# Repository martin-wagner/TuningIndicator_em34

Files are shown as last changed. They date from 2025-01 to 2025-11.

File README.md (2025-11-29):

TuningIndicator EM34

# TuningIndicator_EM34

Tube in operation

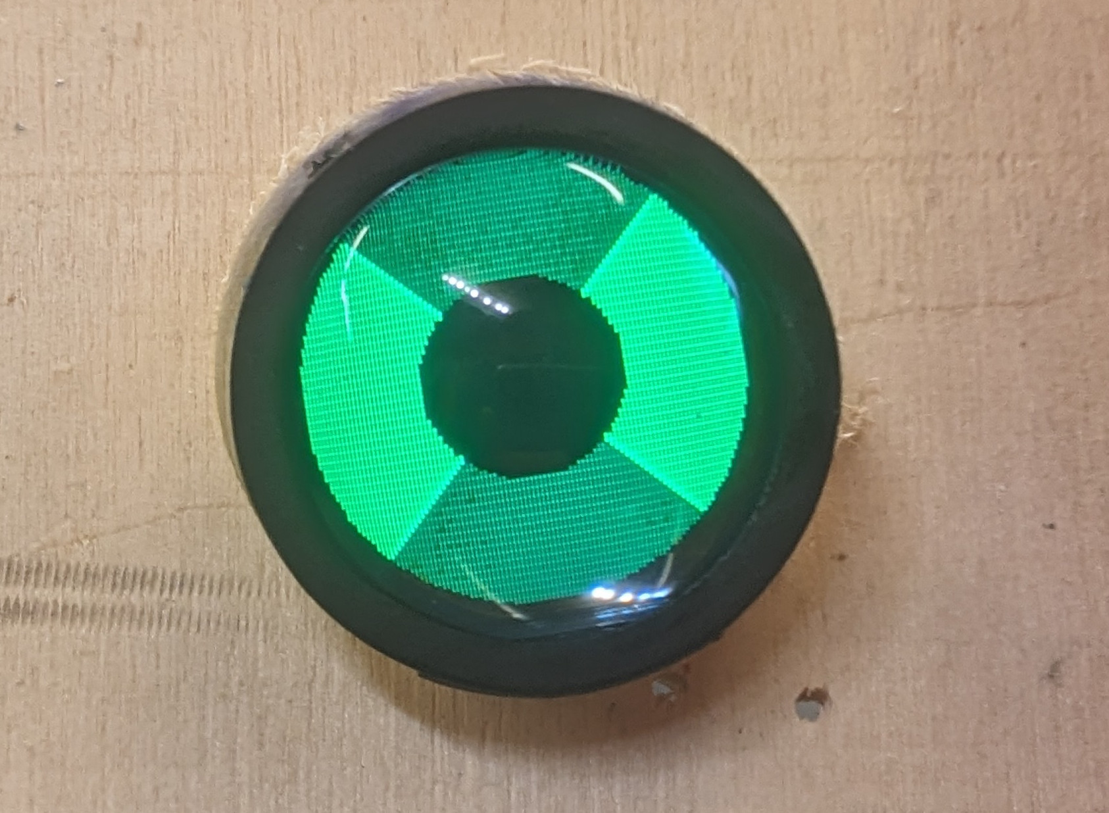
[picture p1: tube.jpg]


Tube in comparision to a Philips EM34

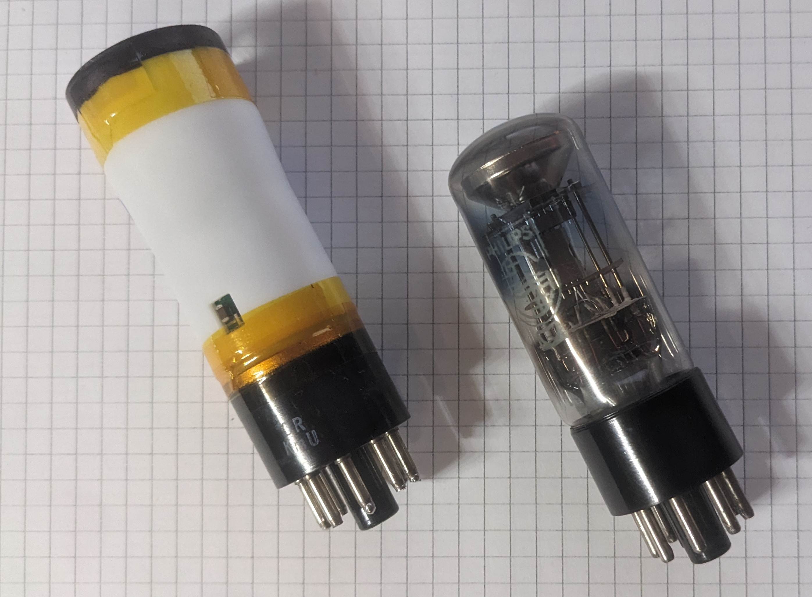
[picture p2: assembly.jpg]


Youtube:

EM34 - Replacement (https://www.youtube.com/watch?v=Ubn03e_z3jU)

## Credits

This project is based on retronics.no 6U5 replacement: https://github.com/donpivo/TuningIndicator_6U5

All PCB design files (KiCAD), fabrication files (gerber), 3D models (.stl) and code (C++, PlatformIO) are shared for personal use only; not for commercial use / sale of neither the complete solution nor parts of it.

## Replacement

The EM34 tube is expensive to buy in good condition and doesn't last that long. "Alternative" tubes only have one shadow angles instead of two.
This project creates a long-lasting tube that mimics the two shadow angles of the EM34, including different sensitivity.

## Building

Follow the guide for the 6U5 tube, it's close enough to the EM34: https://retronics.no/2024/08/29/diy-digital-6u5-magic-eye-replacement/
Be aware to use the EM34 BOM, not the 6U5 one!

### LCD

Can be found on Ebay / Aliexpress for approx. 3 Euro. Search terms: _lcd 0.99 12pin_ . Writing _NFP099-01A_ .

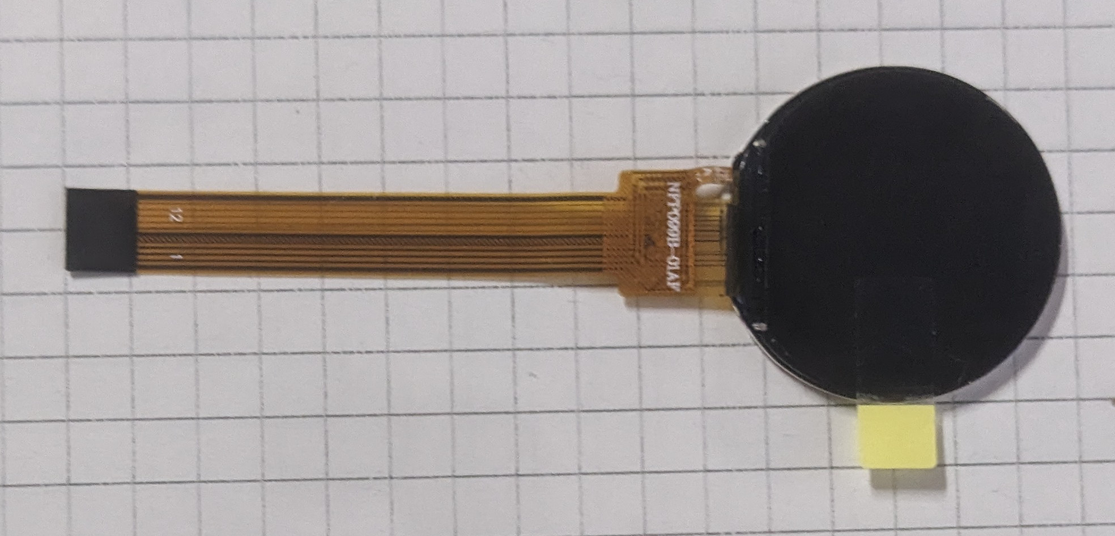
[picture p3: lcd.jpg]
LCD NFP099-01A


### PCB / Housing

Use the gerbers/drill files in cad/pcb/mcu_board/pcb and cad/pcb/octal_base to order at the pcb house of your choise. Use Models/DisplayBracket.stl / Models/EM34-Tube and print/order at the print house of your choise. I've used JLCPCB / JLC3D.

- You need to check your radios schematic for connection of the cathode (see comment in octal_base.pdf).
- I did not use the EMI shield.

### Programming

Use platformio + ST SWD programmer. Either use the programmer on a STM32 devboard or get a ST-LINK/V2 (approx. 15 Euro). Jtag is also exposed on my board, but doesn't have a connector. Use jumper wires to connect SWD to the programmer. The board prints debug info on the serial port.
Be aware that the LCD will not be enabled without pulling the enable pin high (=anode voltage applied)!

### Problems

- The tube is larger compared to a original EM34 (diameter of the top part 30mm instead of 27mm, length 95mm instead of 85mm). Check if your radio will fit a tube of this size!
- The LCD doesn't have good color quality / resolution
- No tube visible when radio is powered off

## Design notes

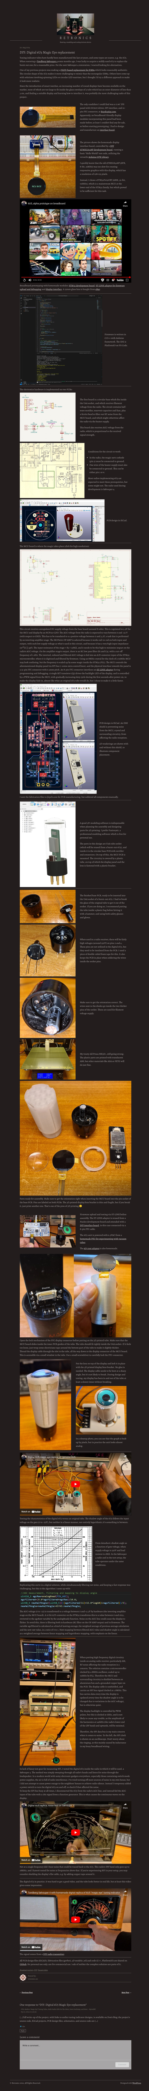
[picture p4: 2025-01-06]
2025-01-06 10.40.33 retronics.no 2fc37c05181f.jpg

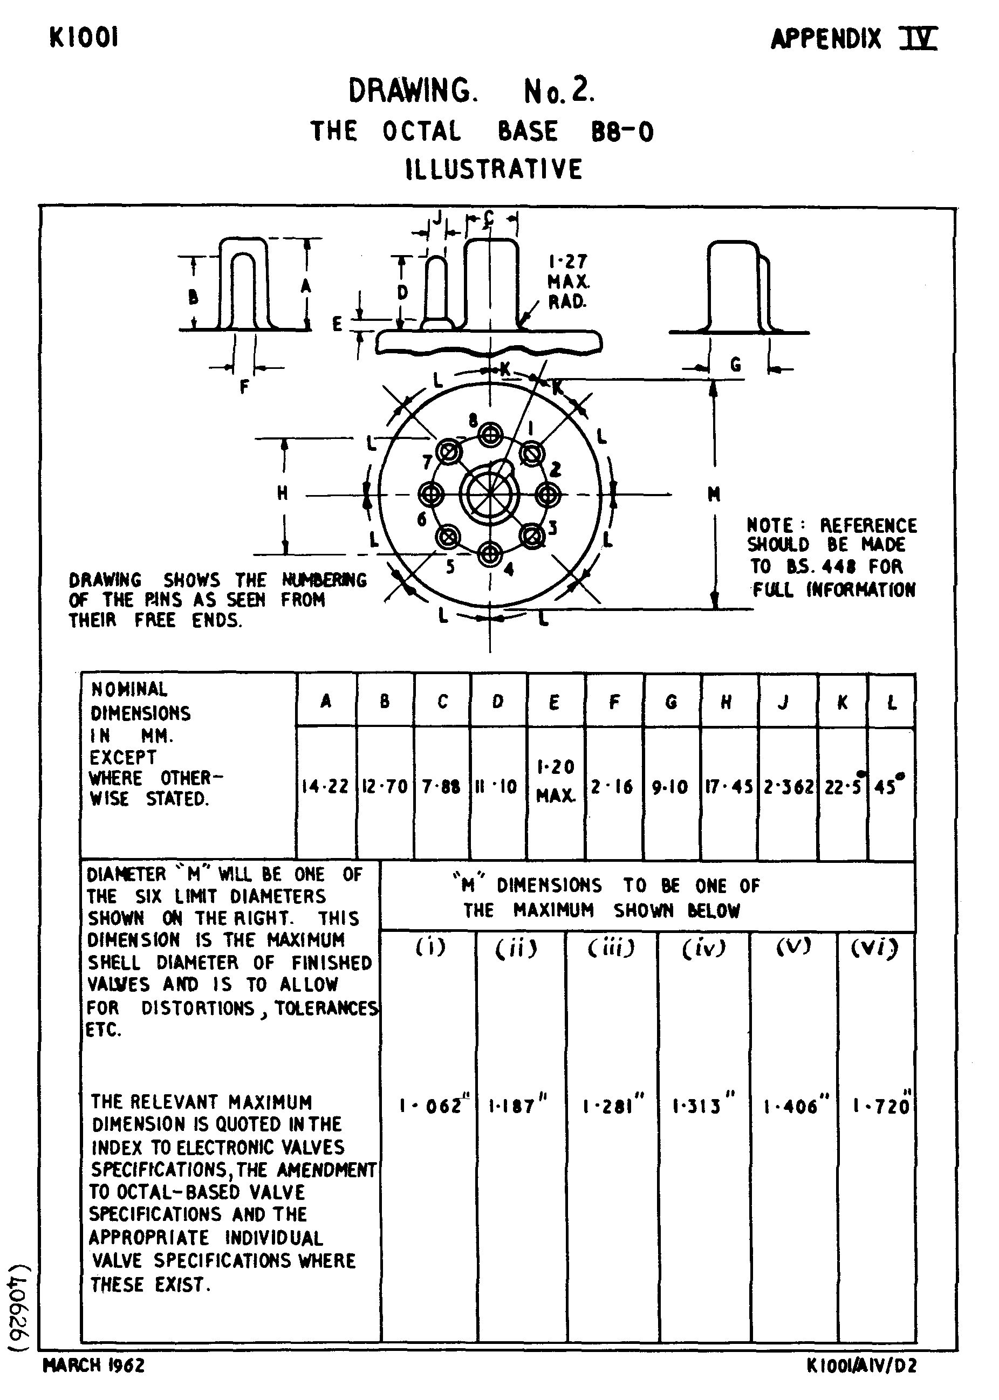
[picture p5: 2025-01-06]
cad/pcb/octal_base/Octal_base.gif

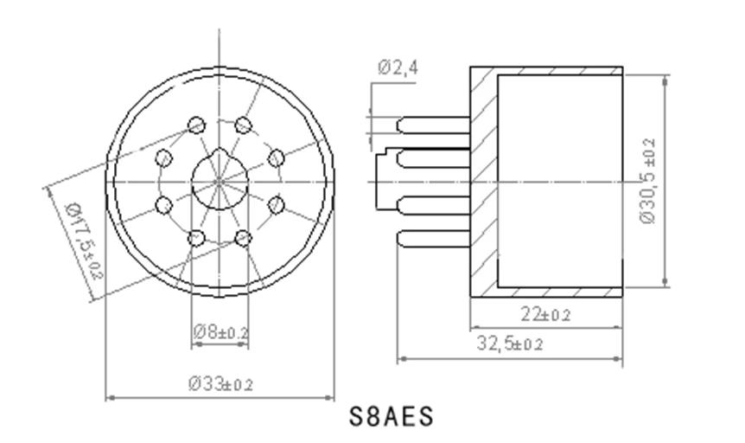
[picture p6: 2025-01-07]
cad/pcb/octal_base/S844fa697d33c40b9b7bb9ba37bb3e9cf7.jpg

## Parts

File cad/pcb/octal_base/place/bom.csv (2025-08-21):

Source: | /home/martin/elektronik/radios/TuningIndicator_em34/cad/pcb/octal_base/octal_base.kicad_sch
Date: | 2025-08-21T12:49:58+0200
Tool: | Eeschema 9.0.4-9.0.4-0~ubuntu24.04.1
Generator: | /usr/share/kicad/plugins/bom_csv_grouped_by_value.py
Component Count: | 11
Collated Components:
Item | Qty | Reference(s) | Value | LibPart | Footprint | Datasheet | DNP | Comments | Datasheet | Description | Footprint | Placement
1 | 1 | C1 | 1000µF 16V | Device:C_Polarized | CP_Radial_D8.0mm_P3.50mm_H21mm | ~ |  |  | ~ | Polarized capacitor | CP_Radial_D8.0mm_P3.50mm_H21mm
2 | 1 | D1 | 3.3V | Device:D_Zener | Diode_SMD:D_0603_1608Metric_Pad1.05x0.95mm_HandSolder | ~ |  |  | ~ | Zener diode | Diode_SMD:D_0603_1608Metric_Pad1.05x0.95mm_HandSolder
3 | 2 | D2, D3 | 1N5819W | Diode:1N5819WS | D_SOD-323_HandSoldering | https://datasheet.lcsc.com/lcsc/2204281430_Guangdong-Hottech-1N5819WS_C191023.pdf |  |  | https://datasheet.lcsc.com/lcsc/2204281430_Guangdong-Hottech-1N5819WS_C191023.pdf | 40V 600mV@1A 1A SOD-323 Schottky Barrier Diodes, SOD-323 | D_SOD-323_HandSoldering
4 | 1 | F1 | T1A | Device:Fuse | Fuse_1206_3216Metric | ~ |  |  | ~ | Fuse | Fuse_1206_3216Metric
5 | 1 | FB1 | 330Ω@100MHz | Device:FerriteBead | L_0805_2012Metric_Pad1.15x1.40mm_HandSolder | ~ |  | 50mΩ@DC | ~ | Ferrite bead | L_0805_2012Metric_Pad1.15x1.40mm_HandSolder
6 | 1 | J1 | Octal Base | Connector_Generic:Conn_01x08 | Library:Valve_Octal_Base | ~ |  |  | ~ | Generic connector, single row, 01x08, script generated (kicad-library-utils/schlib/autogen/connector/) | Library:Valve_Octal_Base
7 | 1 | J2 | Pin Socket | Connector:Conn_01x05_Socket | PinSocket_1x05_P2.54mm_Vertical | ~ |  |  | ~ | Generic connector, single row, 01x05, script generated | PinSocket_1x05_P2.54mm_Vertical
8 | 1 | R1 | 1M | Device:R | Resistor_SMD:R_1206_3216Metric_Pad1.30x1.75mm_HandSolder | ~ |  |  | ~ | Resistor | Resistor_SMD:R_1206_3216Metric_Pad1.30x1.75mm_HandSolder
9 | 1 | R2 | 4k7 | Device:R | Resistor_SMD:R_0603_1608Metric_Pad0.98x0.95mm_HandSolder | ~ |  |  | ~ | Resistor | Resistor_SMD:R_0603_1608Metric_Pad0.98x0.95mm_HandSolder | NP
10 | 1 | R3 | 0 | Device:R | Resistor_SMD:R_0603_1608Metric_Pad0.98x0.95mm_HandSolder | ~ |  |  | ~ | Resistor | Resistor_SMD:R_0603_1608Metric_Pad0.98x0.95mm_HandSolder

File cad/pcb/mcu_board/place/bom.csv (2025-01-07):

Source: | /home/martin/elektronik/radios/TuningIndicator_em34/cad/pcb/mcu_board/mcu_board.kicad_sch
Date: | 2025-01-07T12:11:06+0100
Tool: | Eeschema 8.0.7-8.0.7-0~ubuntu22.04.1
Generator: | /usr/share/kicad/plugins/bom_csv_grouped_by_value.py
Component Count: | 40
Collated Components:
Item | Qty | Reference(s) | Value | LibPart | Footprint | Datasheet | DNP | Comments | Datasheet | Description | Footprint | Place
1 | 1 | C1 | 10µF | Device:C_Small | Capacitor_SMD:C_1206_3216Metric_Pad1.33x1.80mm_HandSolder | ~ |  |  | ~ | Unpolarized capacitor, small symbol | Capacitor_SMD:C_1206_3216Metric_Pad1.33x1.80mm_HandSolder
2 | 1 | C2 | 100nF | Device:C | Retronics_Passives:C_0603_1608Metric_Pad1.08x0.95mm_HandSolder | ~ |  |  | ~ | Unpolarized capacitor | Retronics_Passives:C_0603_1608Metric_Pad1.08x0.95mm_HandSolder
3 | 4 | C3, C9, C10, C11 | 100nF | Device:C_Small | Capacitor_SMD:C_0603_1608Metric_Pad1.08x0.95mm_HandSolder | ~ |  |  | ~ | Unpolarized capacitor, small symbol | Capacitor_SMD:C_0603_1608Metric_Pad1.08x0.95mm_HandSolder
4 | 3 | C4, C5, C6 | 10µF | Device:C | Capacitor_SMD:C_1206_3216Metric_Pad1.33x1.80mm_HandSolder | ~ |  |  | ~ | Unpolarized capacitor | Capacitor_SMD:C_1206_3216Metric_Pad1.33x1.80mm_HandSolder
5 | 2 | C7, C8 | 20pF | Device:C_Small | Capacitor_SMD:C_0603_1608Metric_Pad1.08x0.95mm_HandSolder | ~ |  |  | ~ | Unpolarized capacitor, small symbol | Capacitor_SMD:C_0603_1608Metric_Pad1.08x0.95mm_HandSolder
6 | 1 | FB1 | 1kΩ@100MHz 500mΩ@DC | Device:FerriteBead_Small | Inductor_SMD:L_0603_1608Metric_Pad1.05x0.95mm_HandSolder | ~ |  |  | ~ | Ferrite bead, small symbol | Inductor_SMD:L_0603_1608Metric_Pad1.05x0.95mm_HandSolder
7 | 1 | J1 | Pin Header | Connector:Conn_01x05_Pin | Connector_PinHeader_2.54mm:PinHeader_1x05_P2.54mm_Horizontal | ~ |  |  | ~ | Generic connector, single row, 01x05, script generated | Connector_PinHeader_2.54mm:PinHeader_1x05_P2.54mm_Horizontal
8 | 1 | J2 | EMI Shield | Connector_Generic:Conn_01x01 | Retronics_Hardware:EMI_Shield_MS207-10S | ~ |  |  | ~ | Generic connector, single row, 01x01, script generated (kicad-library-utils/schlib/autogen/connector/) | Retronics_Hardware:EMI_Shield_MS207-10S
9 | 6 | J3, J4, J6, J8, J9, J10 | Conn_01x01_Pin | Connector:Conn_01x01_Pin | TestPoint:TestPoint_Pad_D1.5mm | ~ |  |  | ~ | JTMS | TestPoint:TestPoint_Pad_D1.5mm
10 | 1 | J5 | Display interface | Connector_Generic:Conn_01x12 | Retronics_Connectors:505110-1292 | ~ |  |  | ~ | Generic connector, single row, 01x12, script generated (kicad-library-utils/schlib/autogen/connector/) | Retronics_Connectors:505110-1292
11 | 1 | J7 | FFC8 | Connector_Generic:Conn_01x08 | Connector_PinHeader_2.54mm:PinHeader_1x08_P2.54mm_Vertical | ~ |  |  | ~ | Generic connector, single row, 01x08, script generated (kicad-library-utils/schlib/autogen/connector/) | Connector_PinHeader_2.54mm:PinHeader_1x08_P2.54mm_Vertical
12 | 1 | Q1 | BC847C | Transistor_BJT:BC847 | Retronics_Discrete:SOT-23 | http://www.infineon.com/dgdl/Infineon-BC847SERIES_BC848SERIES_BC849SERIES_BC850SERIES-DS-v01_01-en.pdf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 |  |  | http://www.infineon.com/dgdl/Infineon-BC847SERIES_BC848SERIES_BC849SERIES_BC850SERIES-DS-v01_01-en.pdf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 | 0.1A Ic, 45V Vce, NPN Transistor, SOT-23 | Retronics_Discrete:SOT-23
13 | 1 | R1 | 10kΩ | Device:R | Retronics_Passives:R_0603_1608Metric_Pad0.98x0.95mm_HandSolder | ~ |  |  | ~ | Resistor | Retronics_Passives:R_0603_1608Metric_Pad0.98x0.95mm_HandSolder
14 | 1 | R2 | 2.2MΩ | Device:R | Retronics_Passives:R_0603_1608Metric_Pad0.98x0.95mm_HandSolder | ~ |  |  | ~ | Resistor | Retronics_Passives:R_0603_1608Metric_Pad0.98x0.95mm_HandSolder
15 | 1 | R3 | 15MΩ | Device:R | Retronics_Passives:R_0603_1608Metric_Pad0.98x0.95mm_HandSolder | ~ |  |  | ~ | Resistor | Retronics_Passives:R_0603_1608Metric_Pad0.98x0.95mm_HandSolder
16 | 1 | R4 | 10kΩ | Device:R_Small | Resistor_SMD:R_0603_1608Metric_Pad0.98x0.95mm_HandSolder | ~ |  |  | ~ | Resistor, small symbol | Resistor_SMD:R_0603_1608Metric_Pad0.98x0.95mm_HandSolder
17 | 1 | R5 | 2k7 | Device:R | Resistor_SMD:R_0603_1608Metric_Pad0.98x0.95mm_HandSolder | ~ |  |  | ~ | Resistor | Resistor_SMD:R_0603_1608Metric_Pad0.98x0.95mm_HandSolder
18 | 4 | R6, R7, R8, R9 | 0 | Device:R | Resistor_SMD:R_0603_1608Metric_Pad0.98x0.95mm_HandSolder | ~ |  |  | ~ | Resistor | Resistor_SMD:R_0603_1608Metric_Pad0.98x0.95mm_HandSolder | NP
19 | 1 | R10 | 4k7 | Device:R | Resistor_SMD:R_0603_1608Metric_Pad0.98x0.95mm_HandSolder | ~ |  |  | ~ | Resistor | Resistor_SMD:R_0603_1608Metric_Pad0.98x0.95mm_HandSolder
20 | 1 | R11 | 1MΩ | Device:R_Small | Resistor_SMD:R_0603_1608Metric_Pad0.98x0.95mm_HandSolder | ~ |  |  | ~ | Resistor, small symbol | Resistor_SMD:R_0603_1608Metric_Pad0.98x0.95mm_HandSolder
21 | 1 | R12 | 10Ω | Device:R_Small | Resistor_SMD:R_0603_1608Metric_Pad0.98x0.95mm_HandSolder | ~ |  |  | ~ | Resistor, small symbol | Resistor_SMD:R_0603_1608Metric_Pad0.98x0.95mm_HandSolder
22 | 1 | R13 | 1kΩ | Device:R_Small | Resistor_SMD:R_0603_1608Metric_Pad0.98x0.95mm_HandSolder | ~ |  |  | ~ | Resistor, small symbol | Resistor_SMD:R_0603_1608Metric_Pad0.98x0.95mm_HandSolder
23 | 1 | U1 | MCP6001T-I/OT | Amplifier_Operational:MCP601-xOT | Retronics_IC:SOT-23-5 | http://ww1.microchip.com/downloads/en/DeviceDoc/21314g.pdf |  |  | http://ww1.microchip.com/downloads/en/DeviceDoc/21314g.pdf | Single 2.7V to 6.0V Single Supply CMOS Op Amps, SOT-23-5 | Retronics_IC:SOT-23-5
24 | 1 | U2 | STM32F303CBTx | Retronics_Microcontrollers:STM32F103Cx | Package_QFP:LQFP-48_7x7mm_P0.5mm | http://www.st.com/st-web-ui/static/active/en/resource/technical/document/datasheet/CD00161566.pdf |  |  | http://www.st.com/st-web-ui/static/active/en/resource/technical/document/datasheet/CD00161566.pdf | ARM Cortex-M4 MCU, 128KB flash, 40KB RAM, 72MHz, 2-3.6V, 37 GPIO, LQFP-48 | Package_QFP:LQFP-48_7x7mm_P0.5mm
25 | 1 | U3 | NCP1117-Adj_SOT223 | Regulator_Linear:NCP1117-5.0_SOT223 | Retronics_IC_Power:SOT-223-3_TabPin2 | http://www.onsemi.com/pub_link/Collateral/NCP1117-D.PDF |  |  | http://www.onsemi.com/pub_link/Collateral/NCP1117-D.PDF | 1A Low drop-out regulator, Fixed Output 5V, SOT-223 | Retronics_IC_Power:SOT-223-3_TabPin2
26 | 1 | Y1 | XC32M4-8.000 12pF | Device:Crystal_GND24_Small | Crystal:Crystal_SMD_3225-4Pin_3.2x2.5mm | ~ |  |  | ~ | Four pin crystal, GND on pins 2 and 4, small symbol | Crystal:Crystal_SMD_3225-4Pin_3.2x2.5mm

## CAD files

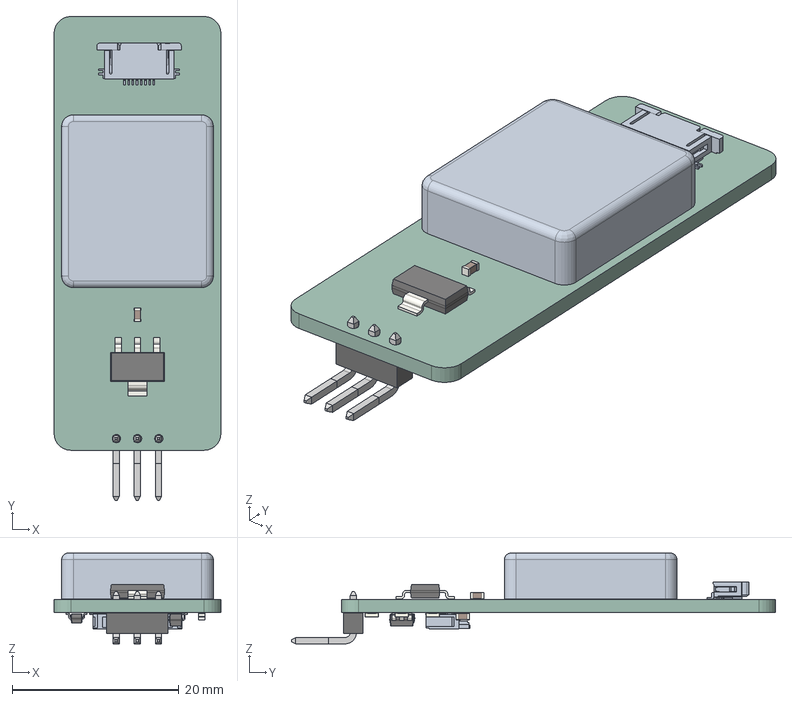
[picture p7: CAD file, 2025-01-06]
cad/pcb/mcu_board/mcu_board.step
20.0 x 58.0 x 10.9 mm
MS207-10S
SOT_223
C_0603_1608Metric x 3
R_0603_1608Metric x 3
SOT_23
SOT_23_5
PinHeader_022052031 v4
U6A_MCU_Board_PCB

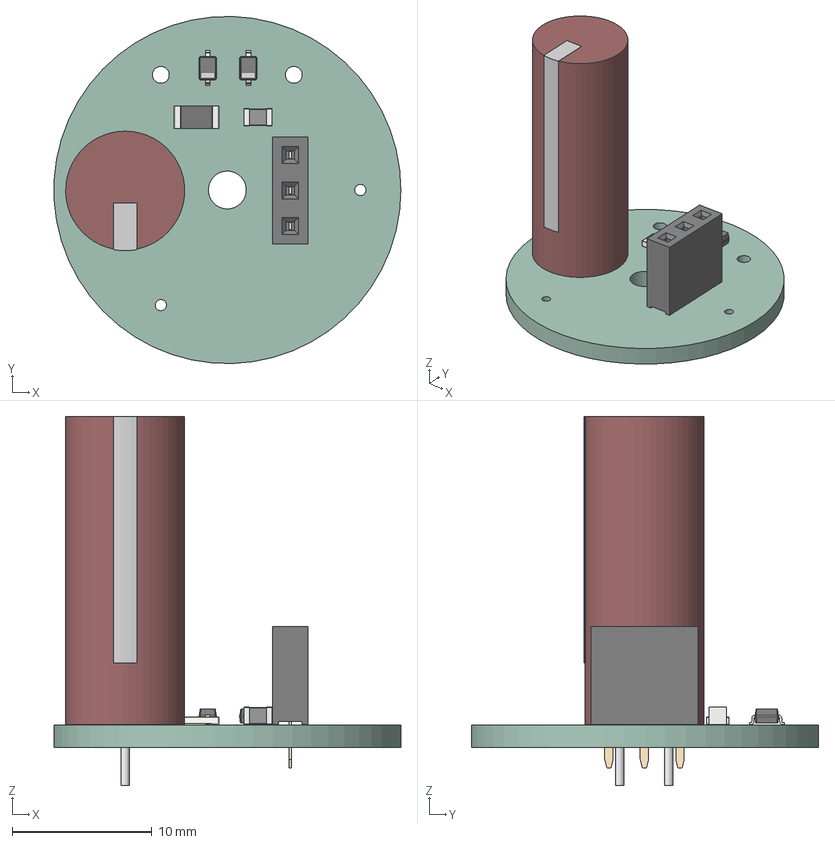
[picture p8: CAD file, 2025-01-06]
cad/pcb/octal_base/octal_base.step
24.8 x 24.8 x 26.4 mm
D_SOD_323 x 2
Fuse_1206_3216Metric
L_0805_2012Metric
PinSocket_1x03_P254mm_Vertical
U6A_Base_PCB

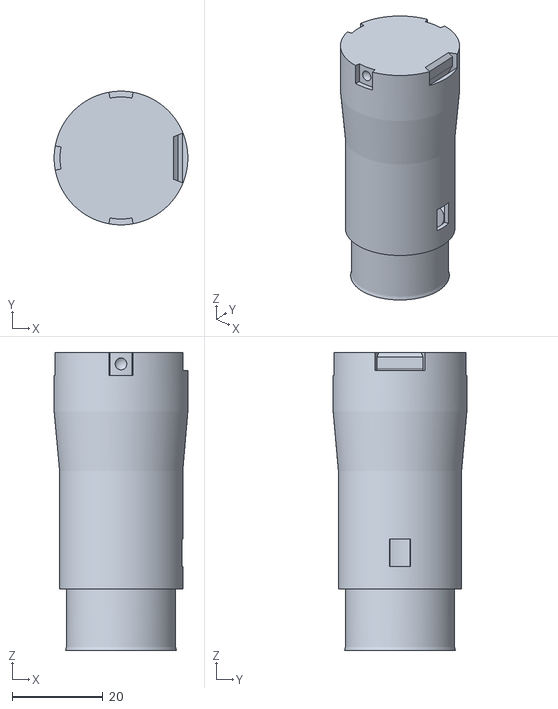
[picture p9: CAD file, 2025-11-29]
Models/em34-Tube.stl
29.4 x 29.4 x 65.5

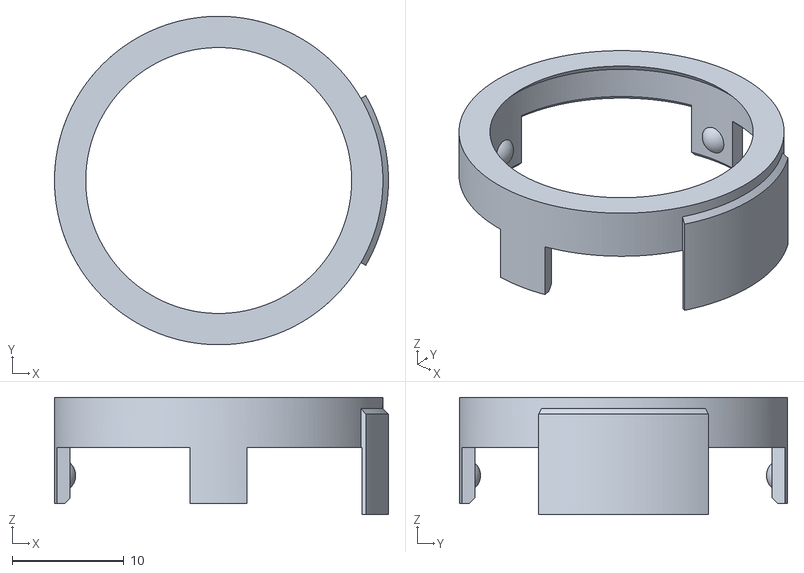
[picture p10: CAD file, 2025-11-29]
Models/DisplayBracket.stl
29.9 x 29.4 x 10.5

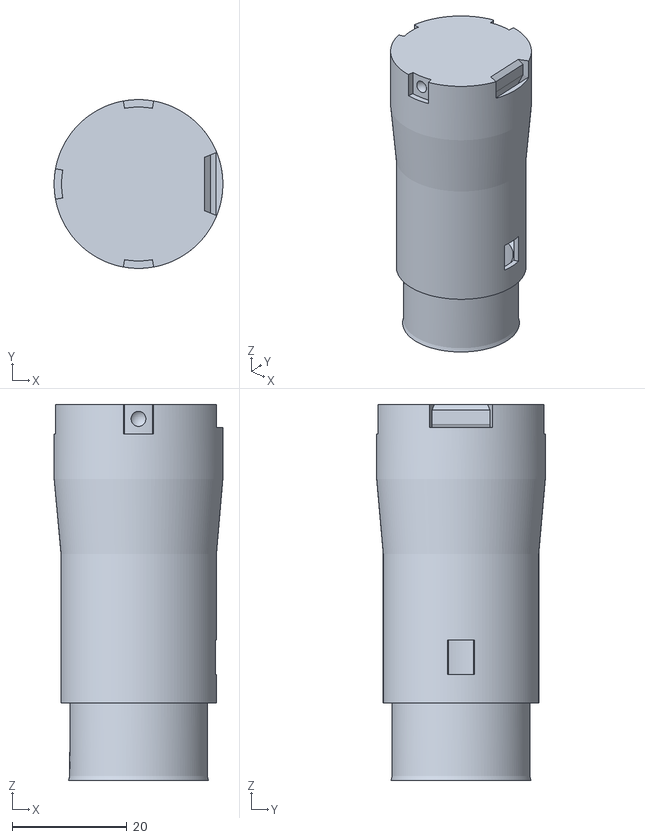
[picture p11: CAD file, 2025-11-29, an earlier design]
Models/archiv/em34-chatgpt.stl
29.4 x 29.4 x 65.5

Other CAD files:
Models/archiv/em34-freecad.FCStd
Models/archiv/6U5_Tube.stl

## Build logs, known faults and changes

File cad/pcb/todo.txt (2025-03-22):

scm

pcb

pcb aufdruck em>>8<<4
pcb aufdruck pin1 lcd fehlt
elko passt nicht
Stecker Debug SWG GND zwischen DIO und CLK, sonst verbindet SWD nicht.

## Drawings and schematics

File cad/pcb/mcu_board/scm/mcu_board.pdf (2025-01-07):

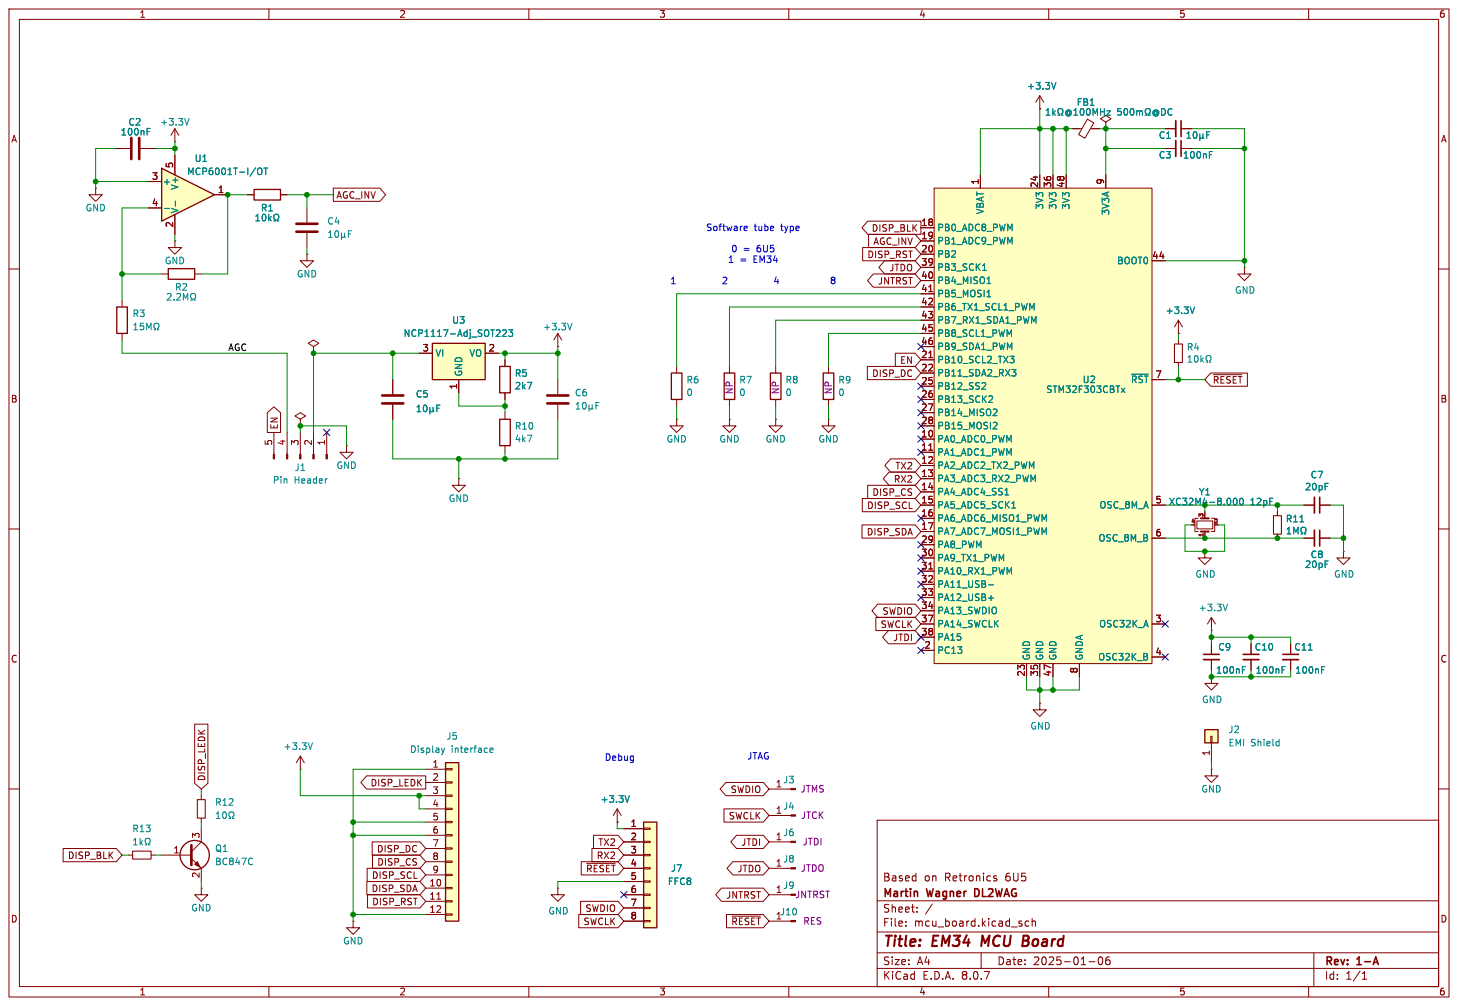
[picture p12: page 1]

1 PA0_ADC0_PWM 10 PA1_ADC1_PWM 11 PA2_ADC2_TX2_PWM 12 PA3_ADC3_RX2_PWM 13 PA4_ADC4_SS1 14 PA5_ADC5_SCK1 15 PA6_ADC6_MISO1_PWM 16 PA7_ADC7_MOSI1_PWM 17 PB0_ADC8_PWM 18 PB1_ADC9_PWM 19 PC13 2 PB2 20 PB10_SCL2_TX3 21 PB11_SDA2_RX3 22 GND 23 3V3 24 PB12_SS2 25 PB13_SCK2 26 PB14_MISO2 27 PB15_MOSI2 28 PA8_PWM 29 OSC32K_A 3 PA9_TX1_PWM 30 PA10_RX1_PWM 31 PA11_USB- 32 PA12_USB+ 33 PA13_SWDIO 34 GND 35 3V3 36 PA14_SWCLK 37 PA15 38 PB3_SCK1 39 OSC32K_B 4 PB4_MISO1 40 PB5_MOSI1 41 PB6_TX1_SCL1_PWM 42 PB7_RX1_SDA1_PWM 43 BOOT0 44 PB8_SCL1_PWM 45 PB9_SDA1_PWM 46 GND 47 3V3 48 OSC_8M_A 5 OSC_8M_B 6 ~{RST}7 GNDA

Id: 1/1 Title: EM34 MCU Board

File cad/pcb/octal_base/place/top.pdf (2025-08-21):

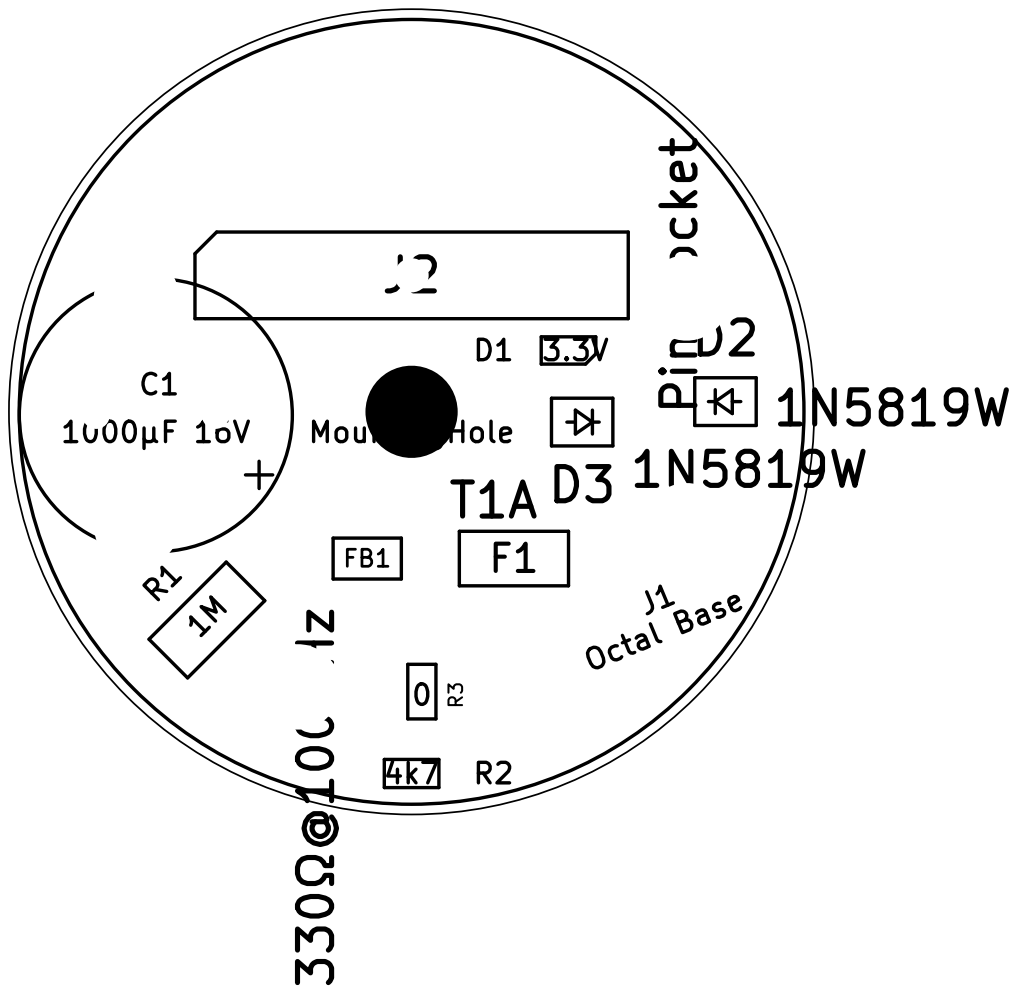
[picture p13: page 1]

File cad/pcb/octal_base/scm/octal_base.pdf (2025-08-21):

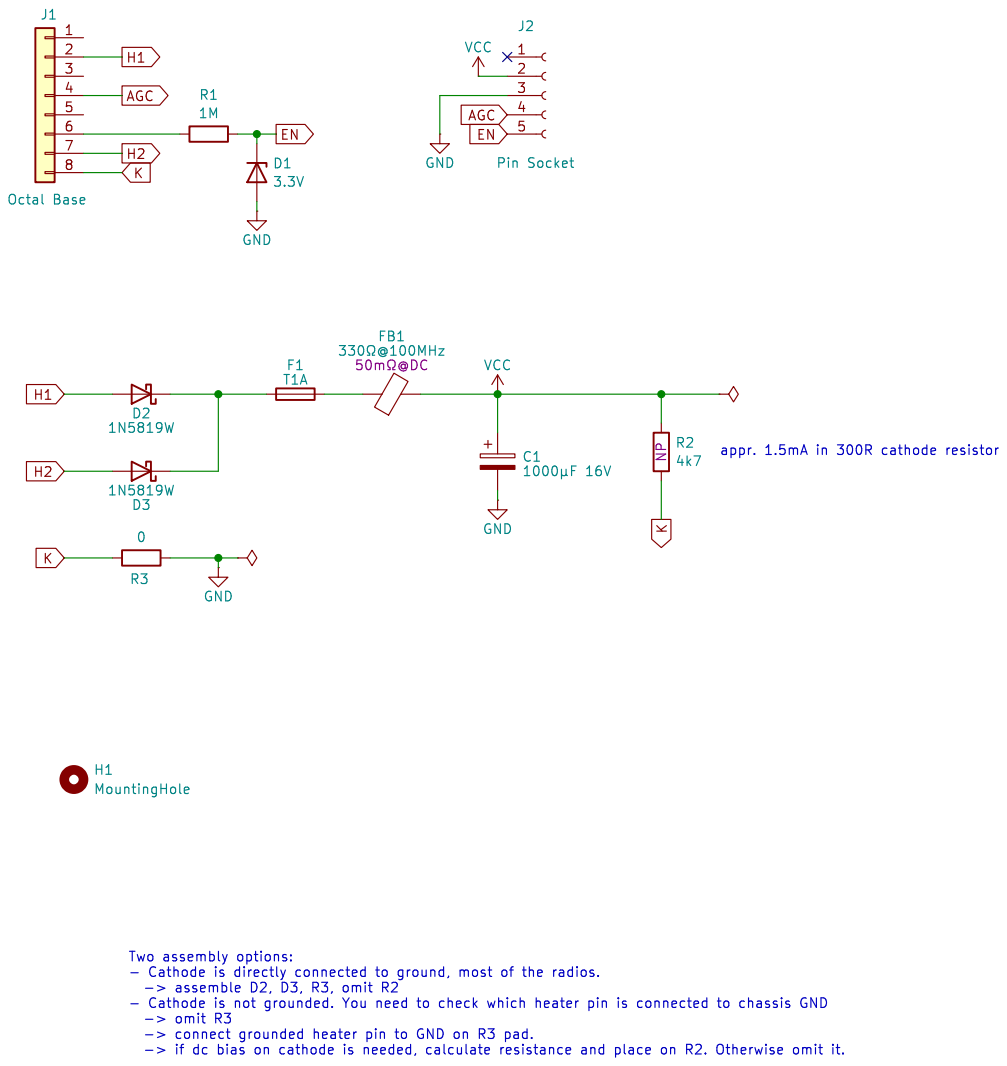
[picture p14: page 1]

Id: 1/1 Title: Adaptor octal base

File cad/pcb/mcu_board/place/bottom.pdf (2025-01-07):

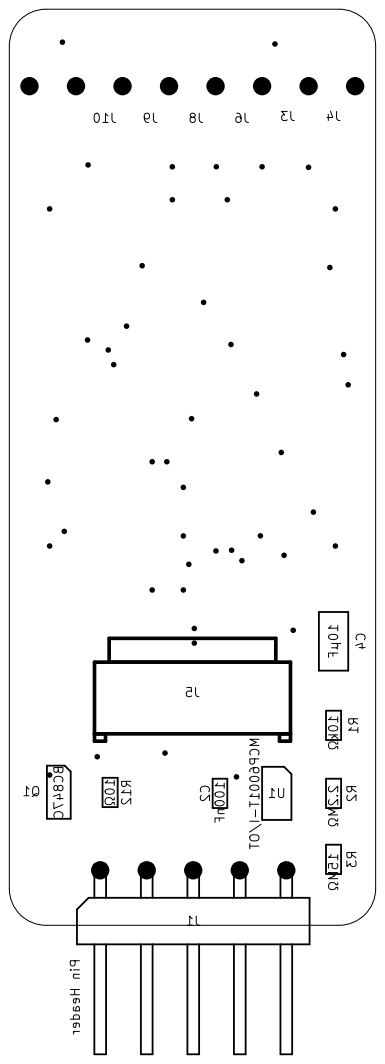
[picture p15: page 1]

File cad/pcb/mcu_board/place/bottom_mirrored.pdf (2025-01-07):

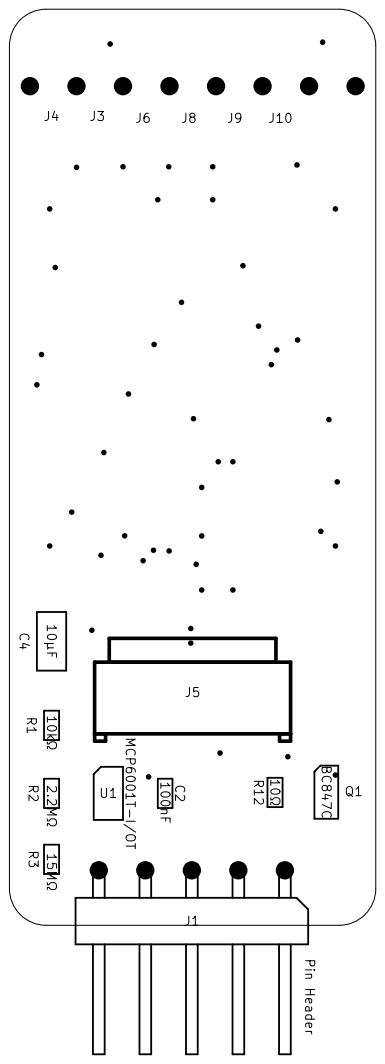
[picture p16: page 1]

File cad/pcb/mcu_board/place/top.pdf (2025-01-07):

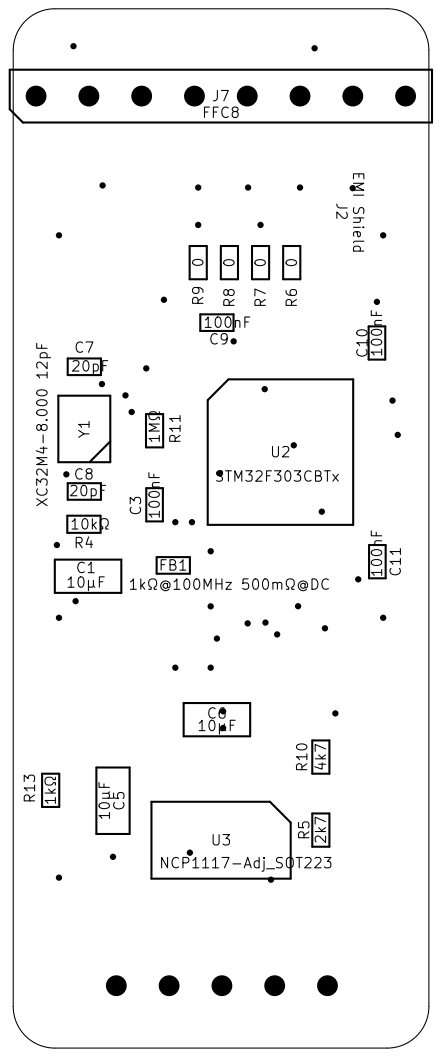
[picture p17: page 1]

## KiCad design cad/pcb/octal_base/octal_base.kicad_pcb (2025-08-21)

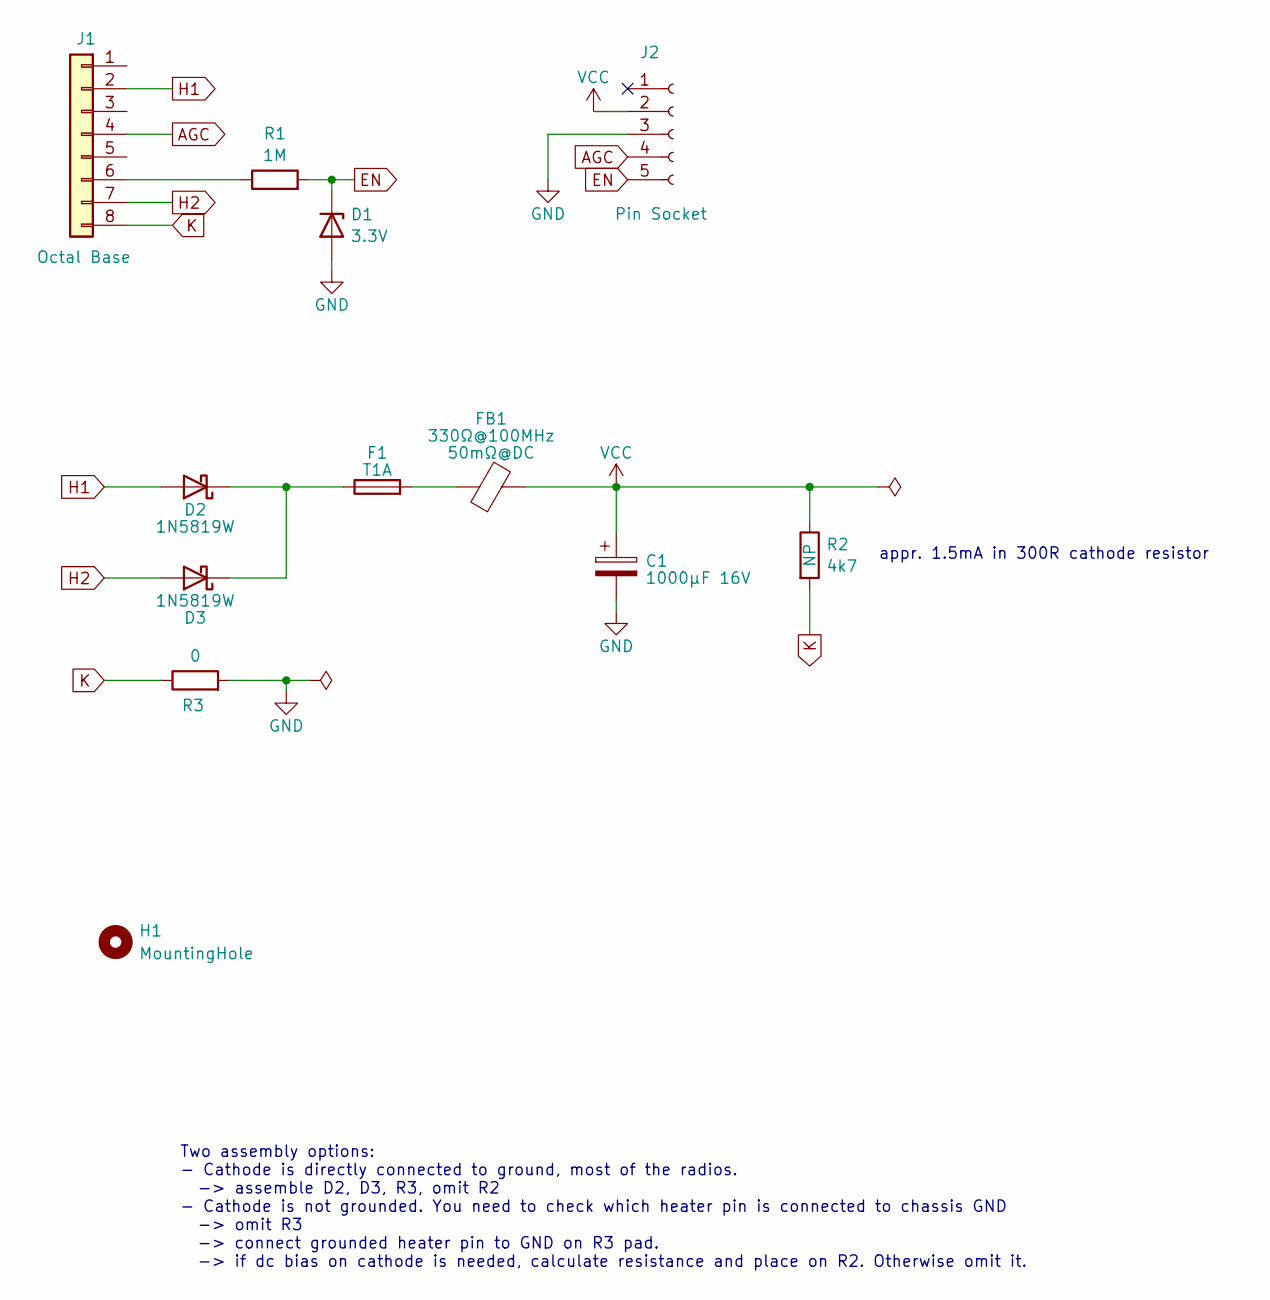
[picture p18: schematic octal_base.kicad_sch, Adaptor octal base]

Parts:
C1: 1000µF 16V; CP_Radial_D8.0mm_P3.50mm_H21mm
D1: 3.3V; D_0603_1608Metric_Pad1.05x0.95mm_HandSolder
D2, D3: 1N5819W; D_SOD-323_HandSoldering
F1: T1A; Fuse_1206_3216Metric
FB1: 330Ω@100MHz; L_0805_2012Metric_Pad1.15x1.40mm_HandSolder
H1: MountingHole; MountingHole_2.7mm_M2.5
J1: Octal Base; Valve_Octal_Base
J2: Pin Socket; PinSocket_1x05_P2.54mm_Vertical
R1: 1M; R_1206_3216Metric_Pad1.30x1.75mm_HandSolder
R2: 4k7; R_0603_1608Metric_Pad0.98x0.95mm_HandSolder
R3: 0; R_0603_1608Metric_Pad0.98x0.95mm_HandSolder

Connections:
AGC: J1.4, J2.4
EN: D1.1 (K), J2.5, R1.2
GND: C1.2, D1.2 (A), J2.3, R3.2
H1: D2.2 (A), J1.2
H2: D3.2 (A), J1.7
K: J1.8, R2.2, R3.1
unnamed: D2.1 (K), D3.1 (K), F1.1
unnamed: F1.2, FB1.1
unnamed: J1.6, R1.1
VCC: C1.1, FB1.2, J2.2, R2.1

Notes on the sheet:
appr. 1.5mA in 300R cathode resistor
Two assembly options: - Cathode is directly connected to ground, most of the radios. -> assemble D2, D3, R3, omit R2 - Cathode is not grounded. You need to check which heater pin is connected to chassis GND -> omit R3 -> connect grounded heater pin to GND on R3 pad. -> if dc bias on cathode is need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

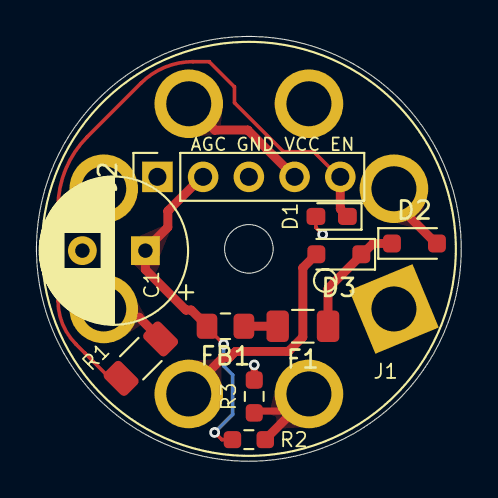
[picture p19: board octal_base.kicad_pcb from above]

Board: 2 copper layers, 23.6 x 23.6 mm, 12 parts (0 on the bottom side), 10 nets.

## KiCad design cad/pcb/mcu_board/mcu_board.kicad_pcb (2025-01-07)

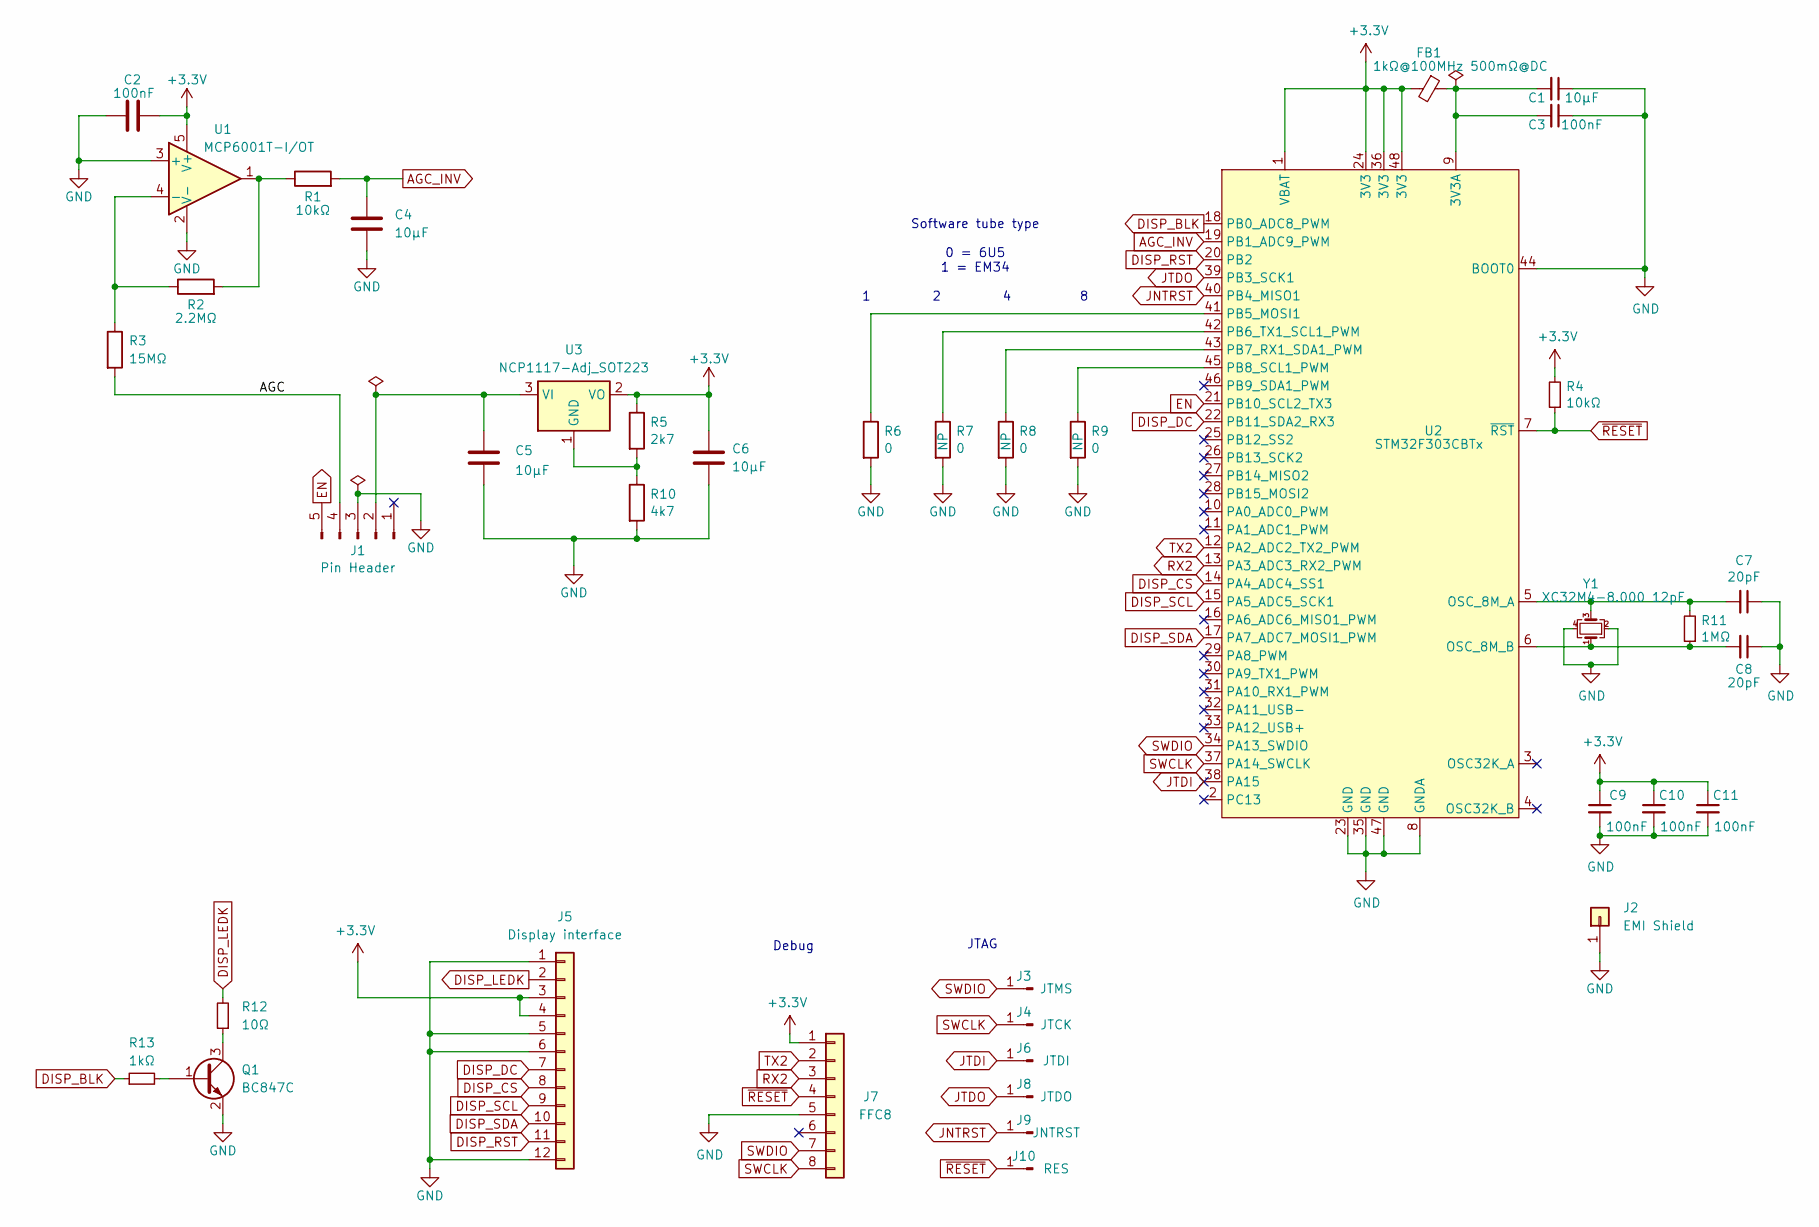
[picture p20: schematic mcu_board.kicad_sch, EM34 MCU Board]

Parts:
C1, C4, C5, C6: 10µF; C_1206_3216Metric_Pad1.33x1.80mm_HandSolder
C2, C3, C9, C10, C11: 100nF; C_0603_1608Metric_Pad1.08x0.95mm_HandSolder
C7, C8: 20pF; C_0603_1608Metric_Pad1.08x0.95mm_HandSolder
FB1: 1kΩ@100MHz 500mΩ@DC; L_0603_1608Metric_Pad1.05x0.95mm_HandSolder
J1: Pin Header; PinHeader_1x05_P2.54mm_Horizontal
J2: EMI Shield; EMI_Shield_MS207-10S
J3, J4, J6, J8, J9, J10: Conn_01x01_Pin; TestPoint_Pad_D1.5mm
J5: Display interface; 505110-1292
J7: FFC8; PinHeader_1x08_P2.54mm_Vertical
Q1: BC847C; SOT-23
R1, R4: 10kΩ; R_0603_1608Metric_Pad0.98x0.95mm_HandSolder
R2: 2.2MΩ; R_0603_1608Metric_Pad0.98x0.95mm_HandSolder
R3: 15MΩ; R_0603_1608Metric_Pad0.98x0.95mm_HandSolder
R5: 2k7; R_0603_1608Metric_Pad0.98x0.95mm_HandSolder
R6, R7, R8, R9: 0; R_0603_1608Metric_Pad0.98x0.95mm_HandSolder
R10: 4k7; R_0603_1608Metric_Pad0.98x0.95mm_HandSolder
R11: 1MΩ; R_0603_1608Metric_Pad0.98x0.95mm_HandSolder
R12: 10Ω; R_0603_1608Metric_Pad0.98x0.95mm_HandSolder
R13: 1kΩ; R_0603_1608Metric_Pad0.98x0.95mm_HandSolder
U1: MCP6001T-I/OT; SOT-23-5
U2: STM32F303CBTx; LQFP-48_7x7mm_P0.5mm
U3: NCP1117-Adj_SOT223; SOT-223-3_TabPin2
Y1: XC32M4-8.000 12pF; Crystal_SMD_3225-4Pin_3.2x2.5mm

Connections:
+3.3V: C2.2, C6.1, C9.1, C10.1, C11.1, FB1.2, J5.3, J5.4, J7.1, R4.2, R5.1, U1.5 (V+), U2.1 (VBAT), U2.24 (3V3), U2.36 (3V3), U2.48 (3V3), U3.2 (VO)
/AGC: J1.4, R3.2
AGC_INV: C4.1, R1.2, U2.19 (PB1_ADC9_PWM)
DISP_BLK: R13.1, U2.18 (PB0_ADC8_PWM)
DISP_CS: J5.8, U2.14 (PA4_ADC4_SS1)
DISP_DC: J5.7, U2.22 (PB11_SDA2_RX3)
DISP_LEDK: J5.2, R12.2
DISP_RST: J5.11, U2.20 (PB2)
DISP_SCL: J5.9, U2.15 (PA5_ADC5_SCK1)
DISP_SDA: J5.10, U2.17 (PA7_ADC7_MOSI1_PWM)
EN: J1.5, U2.21 (PB10_SCL2_TX3)
GND: C1.1, C2.1, C3.1, C4.2, C5.2, C6.2, C7.1, C8.1, C9.2, C10.2, C11.2, J1.3, J2.1, J5.1, J5.5, J5.6, J5.12, J7.5, Q1.2 (E), R6.2, R7.2, R8.2, R9.2, R10.2, U1.2 (V-), U1.3 (+), U2.8 (GNDA), U2.23 (GND), U2.35 (GND), U2.44 (BOOT0), U2.47 (GND), Y1.2, Y1.4
JNTRST: J9.1, U2.40 (PB4_MISO1)
JTDI: J6.1, U2.38 (PA15)
JTDO: J8.1, U2.39 (PB3_SCK1)
unnamed: C5.1, J1.2, U3.3 (VI)
unnamed: Q1.1 (B), R13.2
unnamed: Q1.3 (C), R12.1
unnamed: R1.1, R2.2, U1.1
unnamed: R2.1, R3.1, U1.4 (-)
unnamed: C1.2, C3.2, FB1.1, U2.9 (3V3A)
unnamed: C7.2, R11.2, U2.5 (OSC_8M_A), Y1.3
unnamed: C8.2, R11.1, U2.6 (OSC_8M_B), Y1.1
unnamed: R6.1, U2.41 (PB5_MOSI1)
unnamed: R7.1, U2.42 (PB6_TX1_SCL1_PWM)
unnamed: R8.1, U2.43 (PB7_RX1_SDA1_PWM)
unnamed: R9.1, U2.45 (PB8_SCL1_PWM)
unnamed: R5.2, R10.1, U3.1 (GND)
RX2: J7.3, U2.13 (PA3_ADC3_RX2_PWM)
SWCLK: J4.1, J7.8, U2.37 (PA14_SWCLK)
SWDIO: J3.1, J7.7, U2.34 (PA13_SWDIO)
TX2: J7.2, U2.12 (PA2_ADC2_TX2_PWM)
~RESET: J7.4, J10.1, R4.1, U2.7 (~RST)

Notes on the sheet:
JTAG
Debug
Software tube type 0 = 6U5 1 = EM34 1 2 4 8

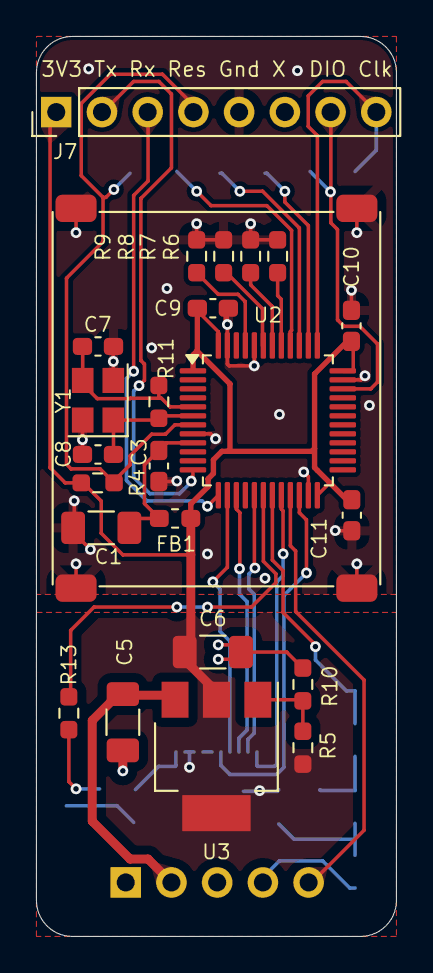
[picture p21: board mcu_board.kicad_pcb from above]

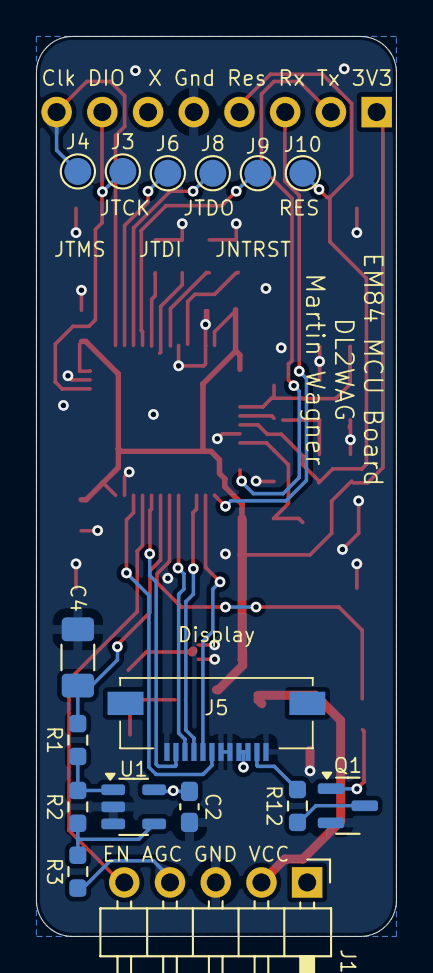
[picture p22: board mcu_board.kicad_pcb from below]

Board: 2 copper layers, 20.0 x 50.0 mm, 40 parts (16 on the bottom side), 33 nets.

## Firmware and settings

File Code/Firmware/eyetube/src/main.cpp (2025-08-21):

/*
 6U5 Digital Replica by retronics.no
 EM34 Digital Replica by Martin Wagner DL2WAG
 */

#include <Arduino.h> 
#include <Arduino_GFX_Library.h> //https://github.com/moononournation/Arduino_GFX | GFX Library for Arduino@^1.4.7
#include <math.h>

#include "tube_base.h"

#define PIN_BACKLIGHT PB0
#define PIN_DC PB11 
#define PIN_CS PA4  
#define PIN_RES PB2
#define PIN_EN PB10
#define PIN_TYPE0 PB5
#define PIN_TYPE1 PB6
#define PIN_TYPE2 PB7
#define PIN_TYPE3 PB8

// PIN_SCL A5
// PIN_SDA A7
#define PIN_AGC PB1
#define BRIGHTNESS 255 // Max 255

Arduino_DataBus *bus = new Arduino_HWSPI(PIN_DC, PIN_CS);
Arduino_GFX *gfx = new Arduino_GC9107(bus, PIN_RES, 0 /* rotation */,
    true /* IPS */, GC9107_TFTWIDTH, GC9107_TFTHEIGHT, 0, 0, 0, 0);
HardwareSerial uart2(PA3, PA2);
Eyetube *tube;

uint8_t fadeInCounter = 0;
uint32_t fadeInLastChange = millis();
uint32_t fade = 0;

void setup(void)
{
  uint8_t type;

  analogWriteResolution(16);
  uart2.begin(115200);
  uart2.println("Digital Eye Tube replacement");
  pinMode(PIN_AGC, INPUT);
  pinMode(PIN_BACKLIGHT, OUTPUT);
  pinMode(PIN_EN, INPUT_PULLDOWN);
  pinMode(PIN_TYPE0, INPUT_PULLUP);
  pinMode(PIN_TYPE1, INPUT_PULLUP);
  pinMode(PIN_TYPE2, INPUT_PULLUP);
  pinMode(PIN_TYPE3, INPUT_PULLUP);
  delay(5);
  type = !digitalRead(PIN_TYPE0) | (!digitalRead(PIN_TYPE1) << 1)
      | (!digitalRead(PIN_TYPE2) << 2) | (!digitalRead(PIN_TYPE3) << 3);
  digitalWrite(PIN_BACKLIGHT, LOW);

  //Display startup
  if (!gfx->begin()) {
    uart2.println("gfx->begin() failed!");
    delay(1000);
    NVIC_SystemReset();
  }
  gfx->fillScreen(BLACK);

  switch (static_cast<Eyetube::Type>(type)) {
    case Eyetube::Type::T_6U5:
      uart2.println("Type 6U5");
      tube = Eyetube::create(Eyetube::Type::T_6U5, Eyetube::Color::C_GREEN,
          PIN_BACKLIGHT, -1, uart2, gfx, false);
      break;
    case Eyetube::Type::T_EM34_GREEN:
      uart2.println("Type EM34 Green");
      tube = Eyetube::create(Eyetube::Type::T_EM34_GREEN, Eyetube::Color::C_GREEN,
                PIN_BACKLIGHT, PIN_EN, uart2, gfx, false);
      break;
    case Eyetube::Type::T_EM34_YELLOW:
      uart2.println("Type EM34 Yellow");
      tube = Eyetube::create(Eyetube::Type::T_EM34_YELLOW, Eyetube::Color::C_YELLOW,
          PIN_BACKLIGHT, -1, uart2, gfx, false);
      break;
    case Eyetube::Type::T_EM34_BLUE:
      uart2.println("Type EM34 Blue");
      tube = Eyetube::create(Eyetube::Type::T_EM34_BLUE, Eyetube::Color::C_BLUE,
                PIN_BACKLIGHT, PIN_EN, uart2, gfx, false);
      break;
    default:
      uart2.println("Type reading failed");
      uart2.println(
          "Supported types: 6U5 (" + String((int) Eyetube::Type::T_6U5)
              + "), EM64 (" + String((int) Eyetube::Type::T_6U5) + "). Found: "
              + String(type));
      uart2.println("Reboot...");
      delay(1000);
      NVIC_SystemReset();
  }
  delay(1000);
}

void loop()
{
  //Fade in
  if ((fadeInCounter < BRIGHTNESS)
      && (millis() - fadeInLastChange) > (120 - (fadeInCounter / 4))) {
    fadeInCounter++;
    fade = fadeInCounter * fadeInCounter;
    fadeInLastChange = millis();
  }

  uint16_t agcRaw = analogRead(PIN_AGC);
  tube->run(agcRaw, fade);
}

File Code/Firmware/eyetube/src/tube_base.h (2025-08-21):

#ifndef SRC_TUBE_BASE_H_
#define SRC_TUBE_BASE_H_

#include <Arduino.h>
#include <Arduino_GFX_Library.h> //https://github.com/moononournation/Arduino_GFX | GFX Library for Arduino@^1.4.7

class Eyetube {
  public:
    enum class Type {
      T_6U5 = 0,
      T_EM34_GREEN = 1 << 0,
      T_EM34_YELLOW = 1 << 1,
      T_EM34_BLUE = 1 << 2,
    };
    enum class Color {
      C_GREEN,
      C_YELLOW,
      C_BLUE
    };

    static constexpr uint16_t GREEN_BRIGHT = RGB565(0, 240, 80);
    static constexpr uint16_t GREEN_MEDIUM = RGB565(10, 180, 60);
    static constexpr uint16_t GREEN_DARK = RGB565(20, 60, 25);

    static constexpr uint16_t YELLOW_BRIGHT = RGB565(0xd3, 0xf7, 0x63);
    static constexpr uint16_t YELLOW_MEDIUM = RGB565(0xad, 0xd6, 0x30);
    static constexpr uint16_t YELLOW_DARK = RGB565(0x41, 0x52, 0x0c);

    static constexpr uint16_t BLUE_BRIGHT = RGB565(0x60, 0xcc, 0xb2);
    static constexpr uint16_t BLUE_MEDIUM = RGB565(0x3f, 0x8e, 0x79);
    static constexpr uint16_t BLUE_DARK = RGB565(0x26, 0x56, 0x49);

  public:

    /** factory */
    static Eyetube *create(Type type, Color color, int32_t pinBacklightPwm, int32_t pinEnable, HardwareSerial &uart, Arduino_GFX *gfx, bool print = false);

    /**
     * update display
     *
     * @param agcRaw unfiltered agc raw value 0 ... 1023
     * @param brightness brightness 0 ... 65535
     */
    virtual void run(uint16_t agcRaw, uint16_t brightness) = 0;

  protected:
    static constexpr uint8_t CENTER_X = 63;
    static constexpr uint8_t CENTER_Y = 75;
    static constexpr uint8_t OUTER_RADIUS = 52;
    static constexpr uint8_t INNER_RADIUS = 24;

    Eyetube(Color color, int32_t pinBacklightPwm, int32_t pinEnable, HardwareSerial &uart, Arduino_GFX *gfx, bool print) :
      pinBacklightPwm(pinBacklightPwm), pinEnable(pinEnable), uart(uart), gfx(gfx), print(print)
    {
      switch (color) {
        case Color::C_GREEN:
        default:
          cBright = GREEN_BRIGHT;
          cMedium = GREEN_MEDIUM;
          cDark = GREEN_DARK;
          break;
        case Color::C_YELLOW:
          cBright = YELLOW_BRIGHT;
          cMedium = YELLOW_MEDIUM;
          cDark = YELLOW_DARK;
          break;
        case Color::C_BLUE:
          cBright = BLUE_BRIGHT;
          cMedium = BLUE_MEDIUM;
          cDark = BLUE_DARK;
          break;
      }
    }

    void drawLine(uint16_t angle, uint16_t lineColor)
    {
      double sinVal = sin(angle * 0.0174533);
      double cosVal = cos(angle * 0.0174533);
      gfx->drawLine(CENTER_X + sinVal * INNER_RADIUS,
          CENTER_Y + cosVal * INNER_RADIUS, CENTER_X + sinVal * OUTER_RADIUS,
          CENTER_Y + cosVal * OUTER_RADIUS, lineColor);
      gfx->drawLine(CENTER_X + sinVal * INNER_RADIUS,
          CENTER_Y + 1 + cosVal * INNER_RADIUS, CENTER_X + sinVal * OUTER_RADIUS,
          CENTER_Y + 1 + cosVal * OUTER_RADIUS, lineColor);
    }

  protected:
    uint16_t cBright;
    uint16_t cMedium;
    uint16_t cDark;

    int32_t pinBacklightPwm;
    int32_t pinEnable;
    HardwareSerial &uart;
    Arduino_GFX *gfx;
    bool print;
};

#endif /* SRC_TUBE_BASE_H_ */

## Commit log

2025-01-06 Add: original project doc, Change: move files
    [mcu_board.kicad_pcb, mcu_board.kicad_sch, mcu_board.step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]
2025-01-06 add: cad gitignore
2025-01-06 Change: Use octal socket, Add: Anode voltage detection
    change pin socket to 5way
    - more stability
    - extra pin
    [octal_base.kicad_sch]
2025-01-06 Change: Pcb to octal
    [octal_base.kicad_pcb, octal_base.kicad_sch]
2025-01-06 Change: Schematic 6U5 -> EM34
    - use generic 1117
    - add software selection straps
    [mcu_board.kicad_sch]
2025-01-06 Fix: EM34 commonly uses cathode resistor, can't use k as gnd
    [octal_base.kicad_pcb]
2025-01-07 Change: Update uC PCB
    [mcu_board.kicad_pcb, mcu_board.kicad_sch]
2025-01-07 Change: Add Jtag, Cleanup
    [mcu_board.kicad_pcb, mcu_board.kicad_sch]
2025-01-07 Add: Base Cleanup
    [octal_base.kicad_pcb]
2025-01-07 Add: manufacturing files
    [bom.csv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]
2025-01-07 Change: Cleanup
    [6U5_MCU_Board.kicad_pcb, 6U5_MCU_Board.kicad_sch, 6U5_MCU_Board.step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]
2025-04-06 Add: Type detection, enable pin (anode voltage detection)
2025-04-06 Change: make classes, preparation for supporting different tube types
2025-08-21 Fix: EM34 socket, don't use bridge rect...
    gnd floats at approx. 1/2 vcc relative to chassis-gnd -- oops.
    [bom.csv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]
2025-11-29 Add: 3d model em34
    [6U5_Tube.stl, DisplayBracket.stl, em34-Tube.stl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]
